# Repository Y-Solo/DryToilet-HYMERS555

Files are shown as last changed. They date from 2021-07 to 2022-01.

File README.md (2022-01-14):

# <p> Toilette sèche pour camping car HYMER S555 de 1993 </p> <i>Dry toilet for HYMER S555 motor home from 1993</i>
Conception d'une toilette sèche en remplacement de la toilette chimique d'origine.
Fabriquée essentiellement à partir de panneaux de bois en contreplaqué d'épaisseur 18mm.

<i>Design of a dry toilet to replace the original chemical toilet. Made primarily from plywood panels 18mm thick.</i>

<br>

<p align="center">
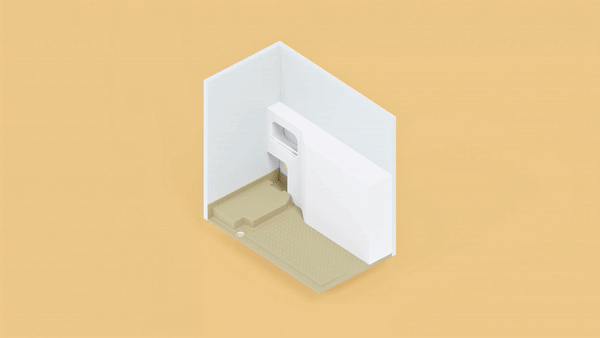
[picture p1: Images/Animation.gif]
  
</p>
<br>

Kit siège + séparateur TROBOLO® utilisé pour cette conception.
Le lien produit : https://trobolo.com/fr/produits/separateur-gris-avec-siege-de-toilette/

<i>TROBOLO® seat + divider kit used for this design.</i>
<i> The product link : https://trobolo.com/en/products/urine-diverting-toilets-insert-grey-toilet-seat/ </i>

<p align="center">
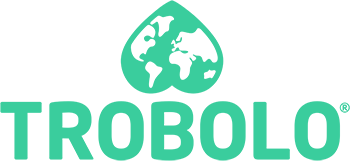
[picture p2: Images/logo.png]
  
</p>

<p align="center">
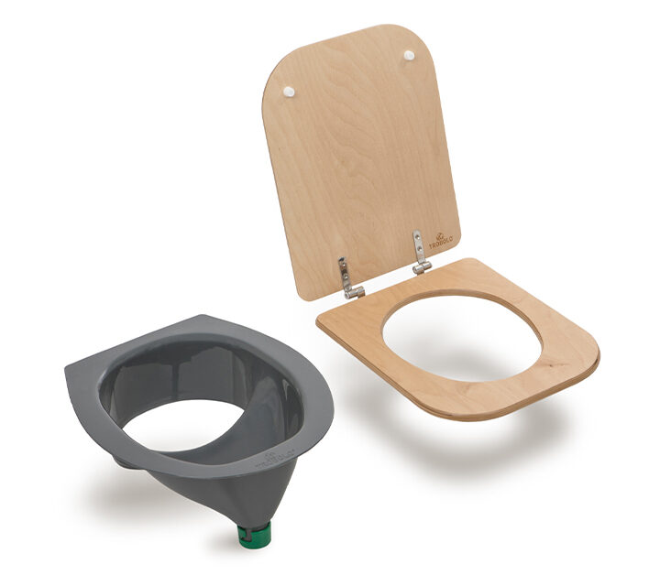
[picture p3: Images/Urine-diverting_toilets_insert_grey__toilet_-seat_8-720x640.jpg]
  
</p>

<br>

# <p> Schéma de la salle d'eau sans toilette </p> <i>Diagram of the bathroom without toilet</i>

<p align="center">
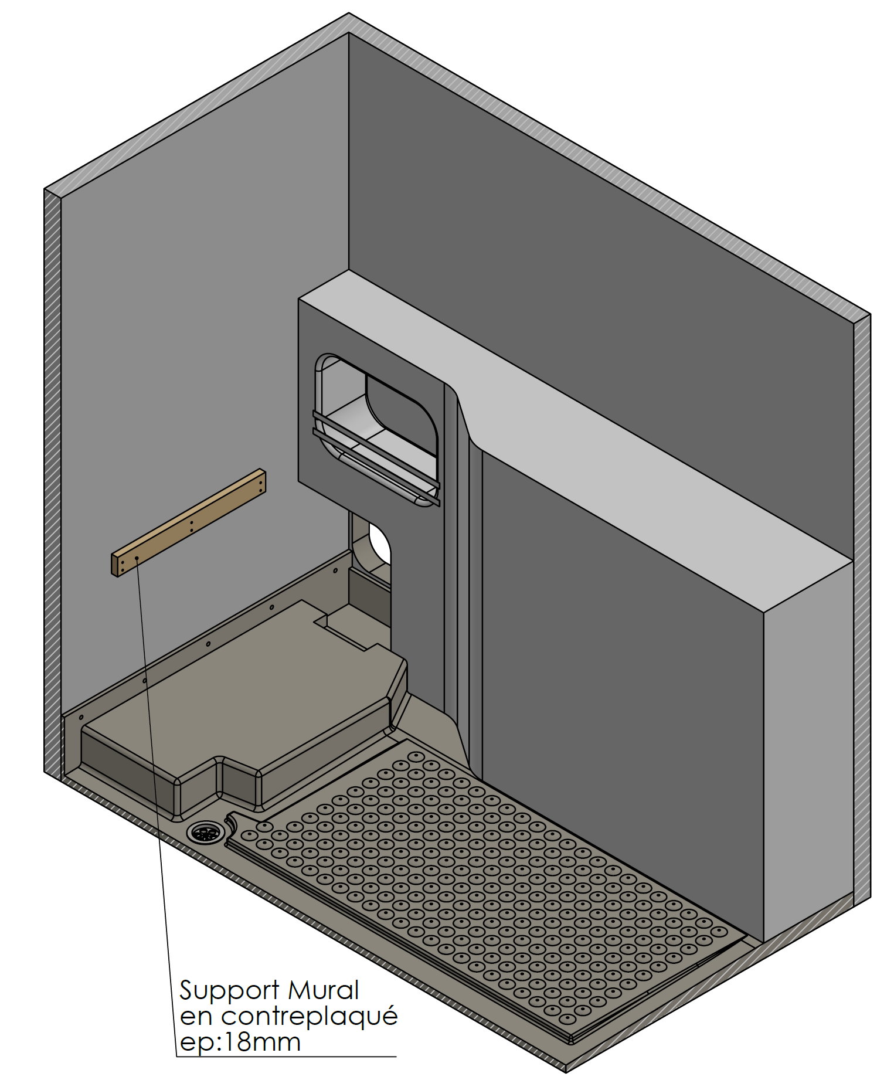
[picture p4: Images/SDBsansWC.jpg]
  
</p>
<br>
<br>

# <p> Schéma de la salle d'eau avec toilette </p> <i>Diagram of the bathroom with toilet</i>

<p align="center">
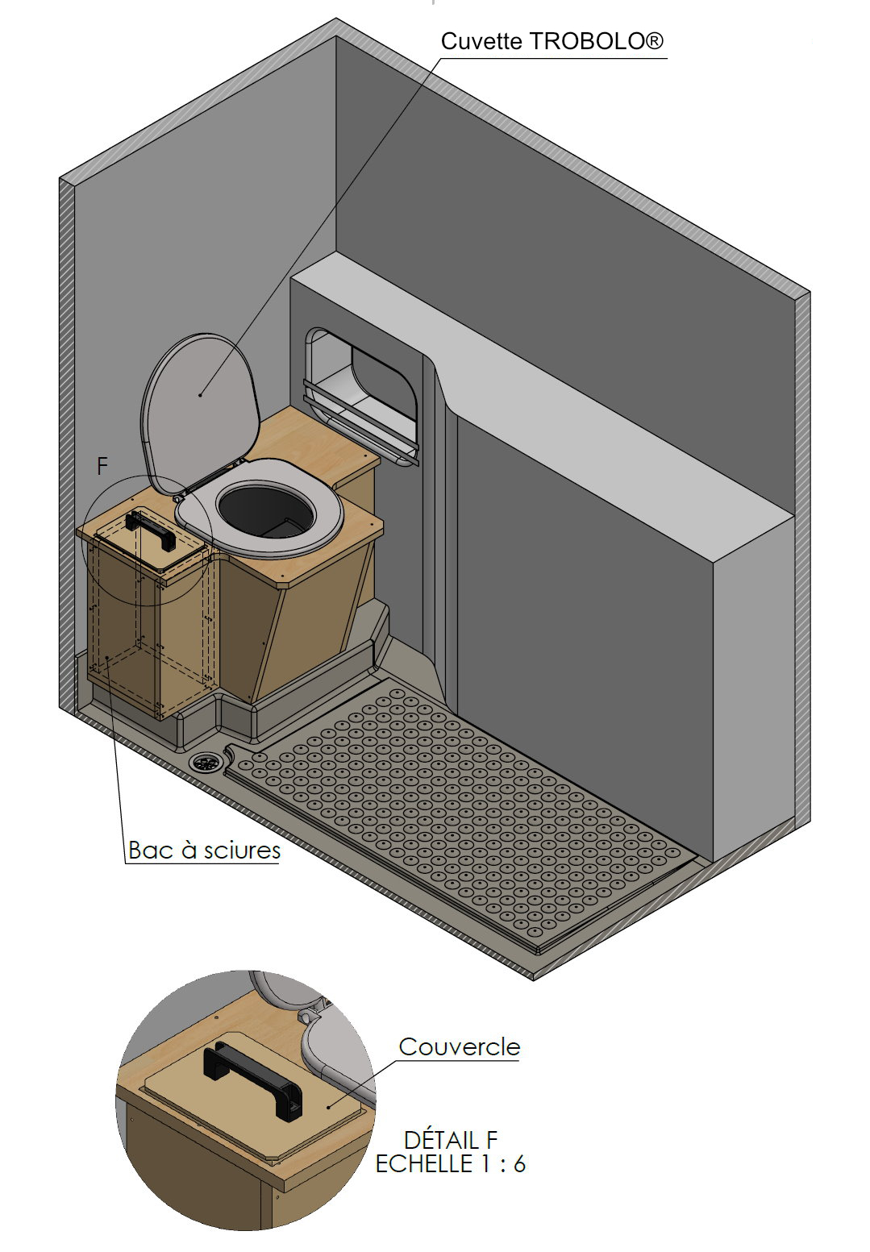
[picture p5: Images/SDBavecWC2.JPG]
  
</p>
<br>
<br>

# <p> Vue éclatée </p> <i>Exploded view</i>

<p align="center">
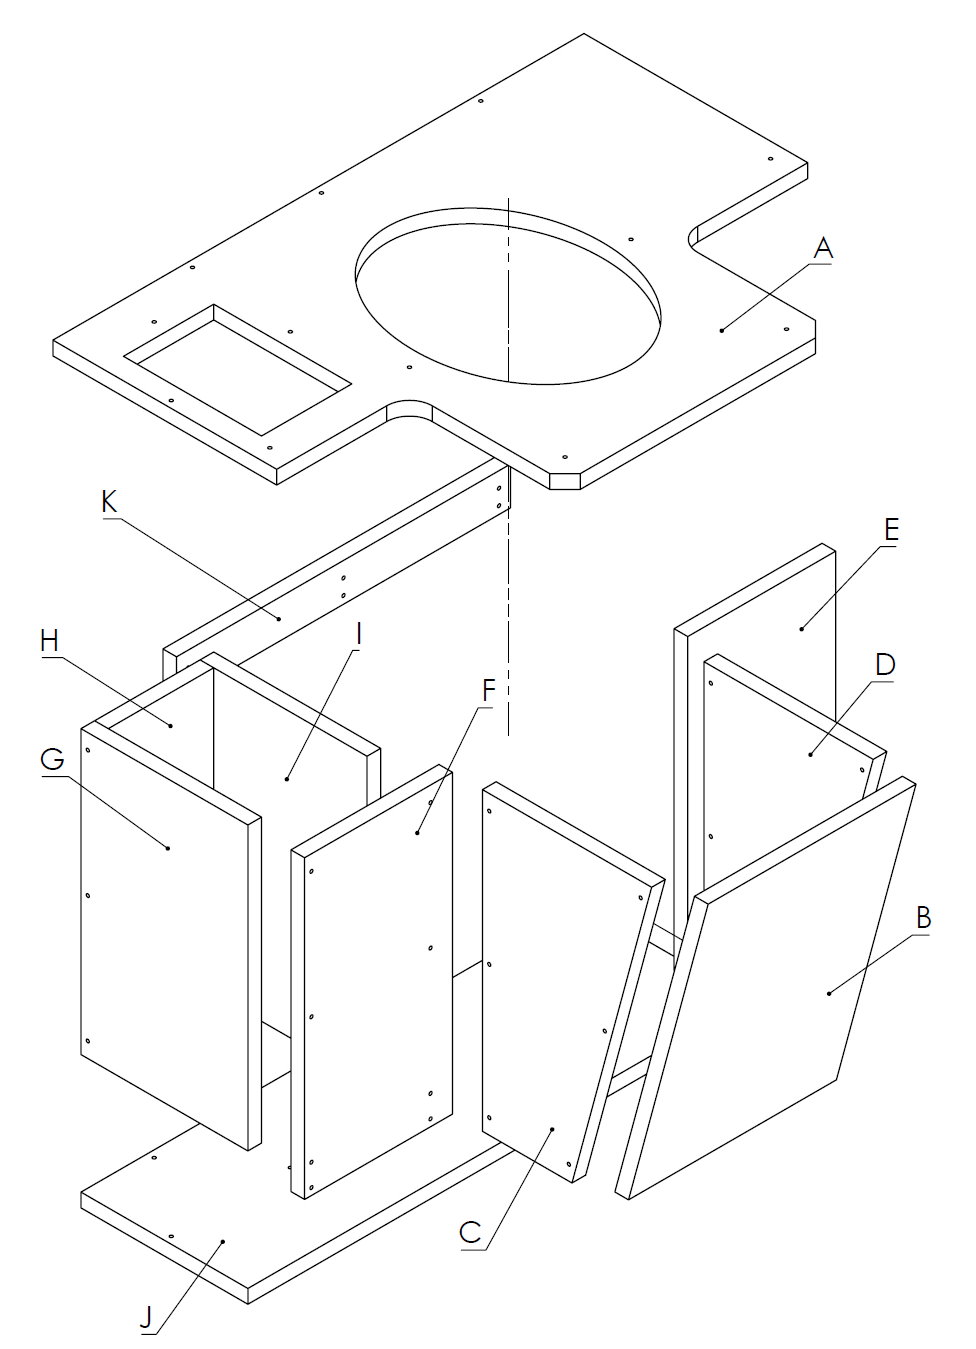
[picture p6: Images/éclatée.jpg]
  
</p>
<p> Voir le plan PDF pour correspondance des nomenclatures </p> <i> See the PDF plan for correspondence of the nomenclatures </i>
<br>
<br>

# <p> Bac à sciures </p> <i>Sawdust bin</i>

<p align="center">
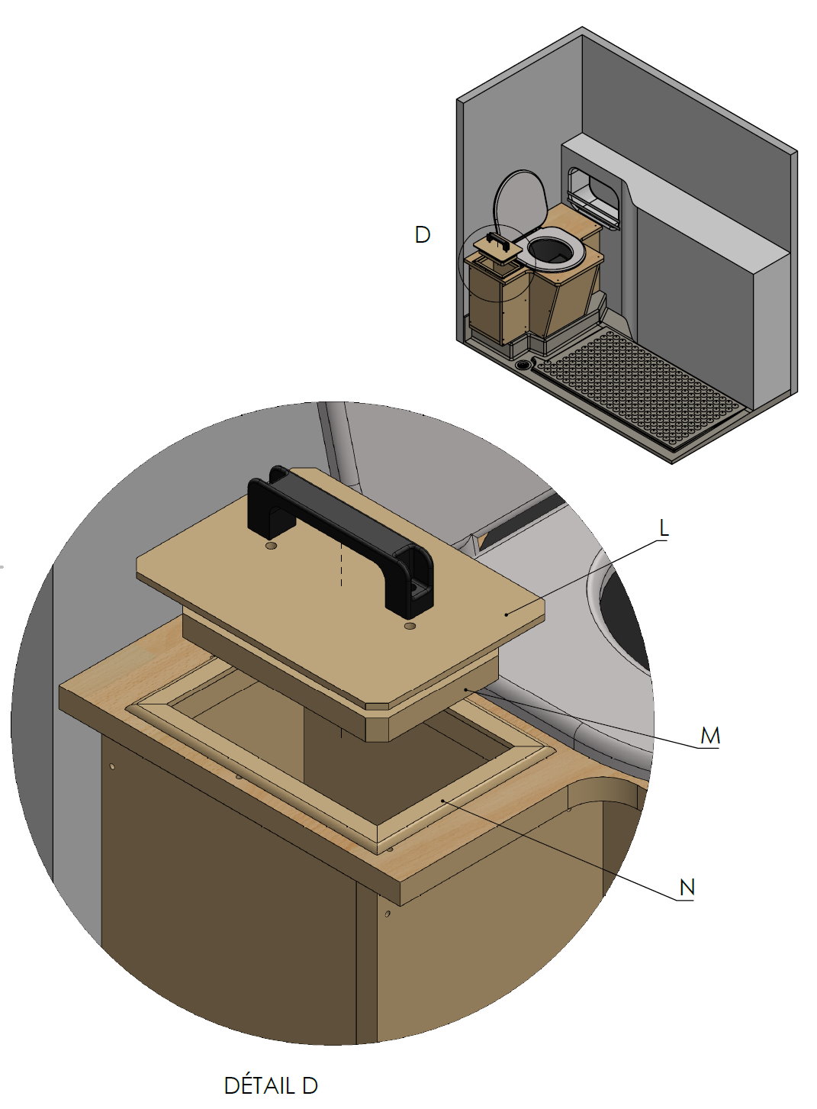
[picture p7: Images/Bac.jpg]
  
</p>
<p> Voir le plan PDF pour correspondance des nomenclatures </p> <i> See the PDF plan for correspondence of the nomenclatures </i>
<br>
<br>

# <p> Résultat final </p> <i> Final result </i>

<p align="center">
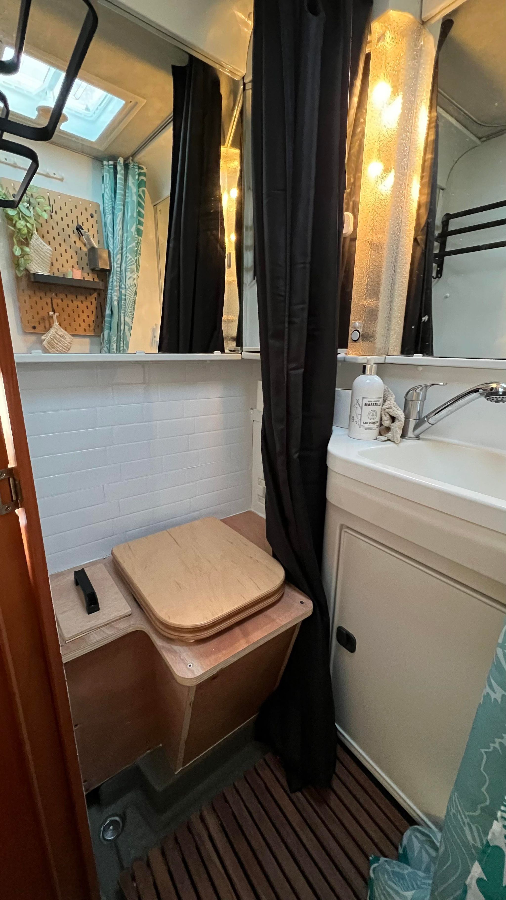
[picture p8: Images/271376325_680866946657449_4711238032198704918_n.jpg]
  
</p>

<br>

----------------------------------------------

<br>

# <p> Outils nécessaires </p> <i> Necessary tools </i>
- Scie Circulaire / <i> Circular saw </i>
- Scie Sauteuse / <i> Jigsaw </i>
- Visseuse Perceuse électrique / <i> Electric drill & screwdriver </i>
- Scie Cloche de 60mm / <i> 60mm diameter hole saw  </i>
- Mètre ruban / <i> Mesureing tape </i>
- Equerre de charpentier / <i> Carpenter's square </i>
- Grande règle en acier (60cm) / <i> Large steel ruler (60cm) </i>
- Crayon à papier / <i> Pencil </i>
- Coffret assortiment de vis à bois / <i> Wood screw assortment box </i>
- Equipements de Protection Individuel (EPI) / <i> Personal Protective Equipment (PPE) </i>

<br>

# <p> Finitions à prévoir </p> <i> Finishes to be expected </i>
- Poncer les pièces après découpe / <i> Sand the parts after cutting </i>
- Application d'un vernis epoxy pour protection du bois contre l'humidité et les projections d'eau de la douche / <i> Application of an epoxy varnish to protect the wood against humidity and splashing water from the shower </i>
- Application de joints silicones contre les infiltrations d'eau tout autour de la structure / <i> Application of silicone seals against water infiltration all around the structure </i>
- Ajout d'un joint feutre pour éviter l'infiltration d'eau dans le bac à sciures (entre les pièces L et N) / <i> Addition of a felt seal to prevent water infiltration into the sawdust bin (between parts L and N) </i>

<br>

# <p> Découpe de l'ouverture pour le séparateur </p> <i> Opening cut for the toilet bowl </i>
La découpe devra être effectuée à l'aide du gabarit en carton fourni avec la cuvette. Trobolo n'a pas pu me fournir les dimensions précises de l'ouverture à découper / 
<i> The cutout should be made using the cardboard template supplied with the toilet bowl. Trobolo do not provide me the precise dimensions of the opening to be cut. </i>

<br>

# <p> Conception, plans et visuels créés par Yannis MICHALET / ARCAD Digital </p> <i> Design, plans and visuals created by Yannis MICHALET / ARCAD Digital </i>

<br>

# https://arcad-digital.com

<br>

# <p> Projet sous licence GNU AGPLv3 </p> <i> Project under GNU AGPLv3 Licence </i>
Permissions d'utilisation / <i> Usage permissions </i> : 
- Utilisation commerciale / <i> Commercial use </i>
- Distribution 
- Modification 
- Utilisation privée / <i> Private use </i>

<br>

Conditions d'utilisation / <i> Terms of use </i> :
- Divulguer les codes sources si modification / <i> Disclose source </i>
- Mentionner l'auteur "Yannis MICHALET / ARCAD Digital" / <i>  License and copyright notice "Yannis MICHALET / ARCAD Digital" </i>

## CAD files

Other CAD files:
DryToilet-HymerS555_RevB2.x_t

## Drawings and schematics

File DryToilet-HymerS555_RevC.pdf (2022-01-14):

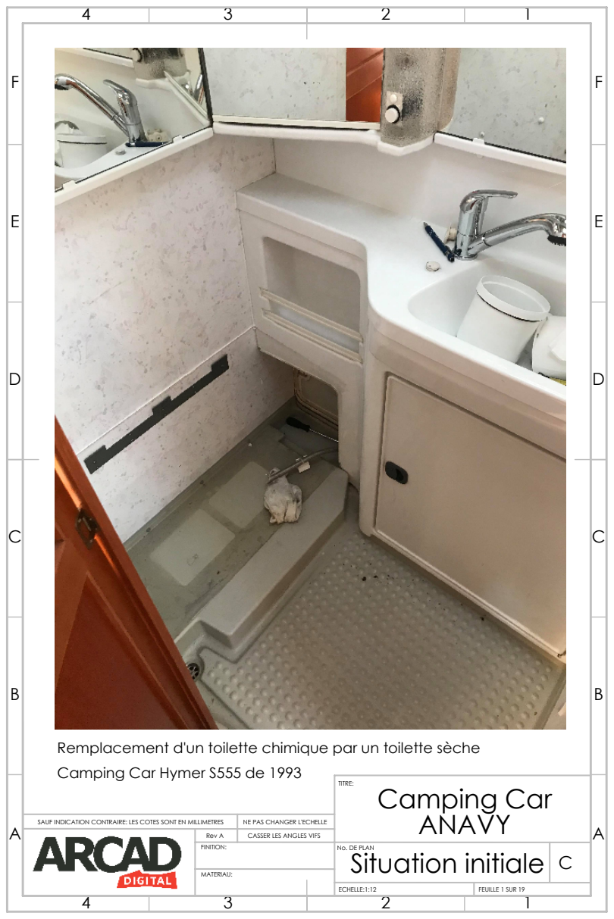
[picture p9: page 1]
Camping Car; CASSER LES ANGLES VIFS

Remplacement d'un toilette chimique par un toilette sèche
Camping Car Hymer S555 de 1993

SAUF INDICATION CONTRAIRE: LES COTES SONT EN MILLIMETRES | NE PAS CHANGER L'ECHELLE

Rev A
FINITION: | No. DE PLAN Situation initiale | C

MATERIAU:

ECHELLE:1:12 | FEUILLE 1 SUR 19

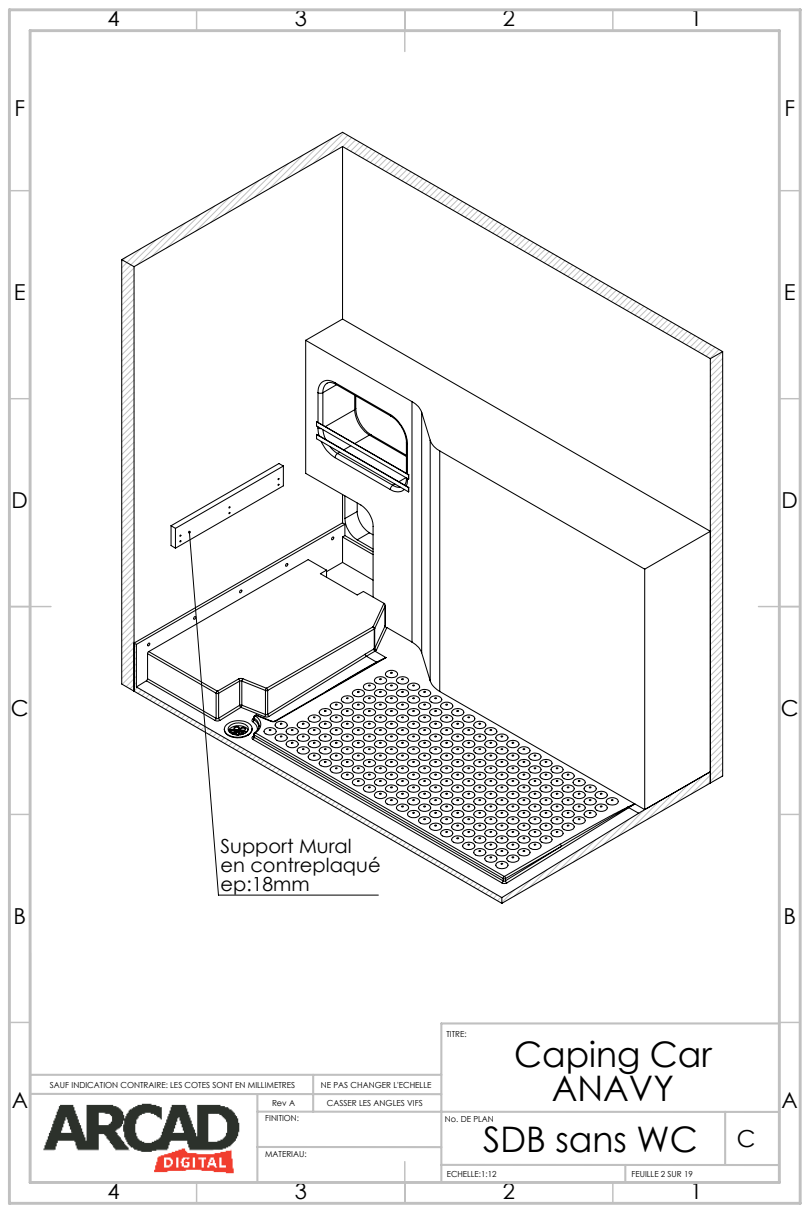
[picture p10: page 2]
Support Mural en contreplaqué; Caping Car; ECHELLE:1:12; FEUILLE 2 SUR 19; CASSER LES ANGLES VIFS

SAUF INDICATION CONTRAIRE: LES COTES SONT EN MILLIMETRES | NE PAS CHANGER L'ECHELLE

Rev A
FINITION: | SDB sans WC | C

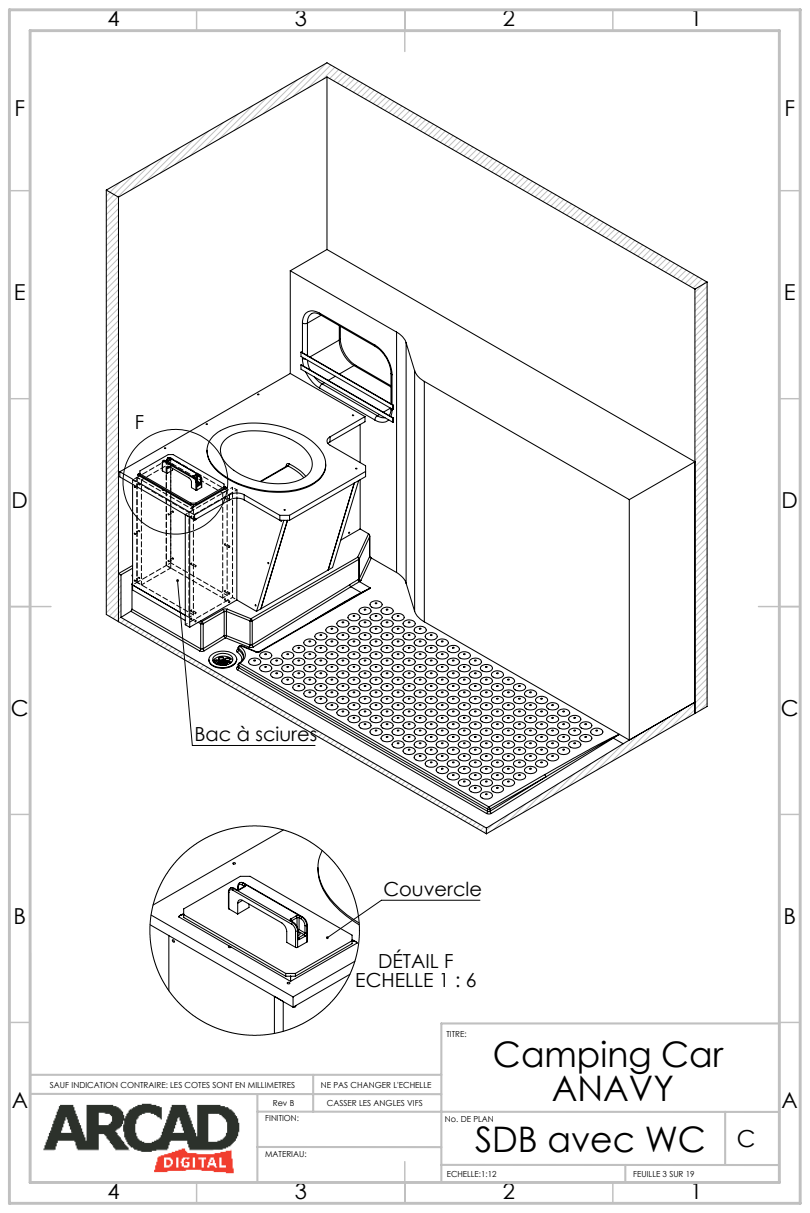
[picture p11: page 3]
Bac à sciures; DÉTAIL F ECHELLE 1 : 6; Camping Car; CASSER LES ANGLES VIFS; FEUILLE 3 SUR 19

SAUF INDICATION CONTRAIRE: LES COTES SONT EN MILLIMETRES | NE PAS CHANGER L'ECHELLE

Rev B
FINITION: | SDB avec WC | C

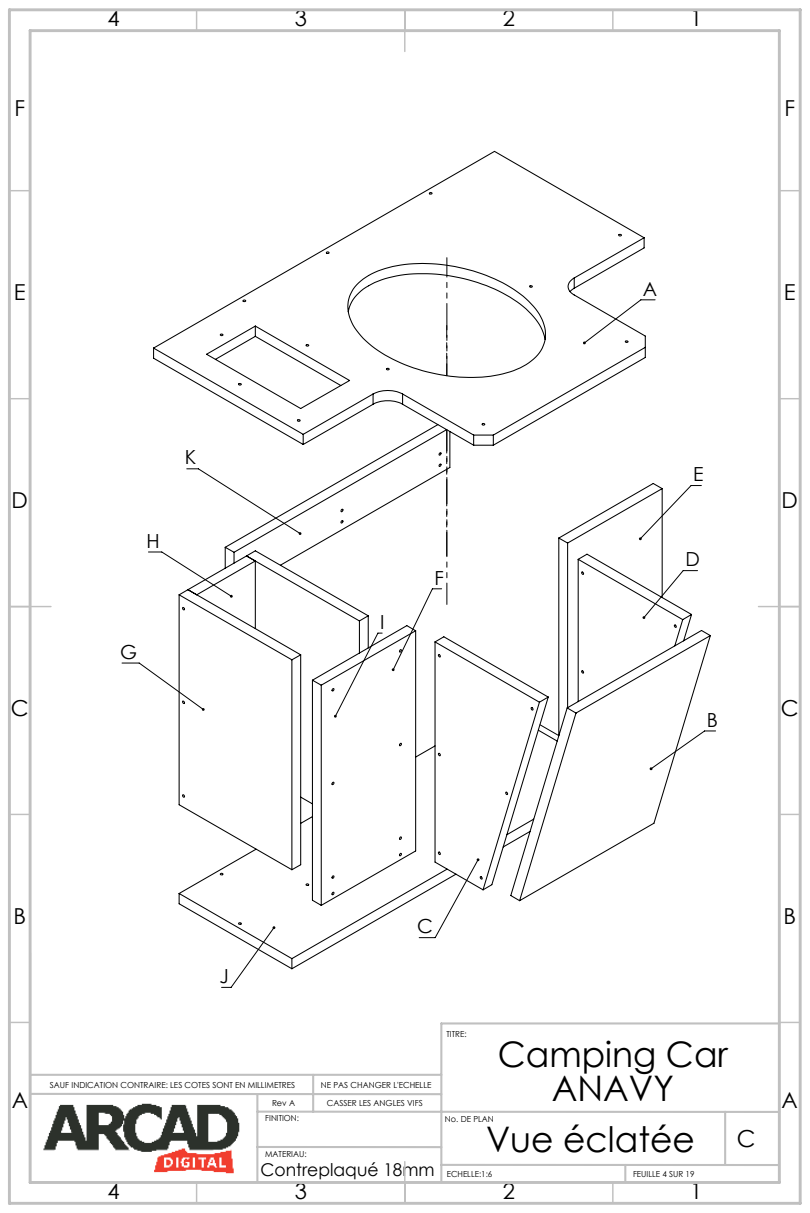
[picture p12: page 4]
Camping Car; CASSER LES ANGLES VIFS

SAUF INDICATION CONTRAIRE: LES COTES SONT EN MILLIMETRES | NE PAS CHANGER L'ECHELLE

Rev A
FINITION: | Vue éclatée | C
Contreplaqué 18mm

FEUILLE 4 SUR 19

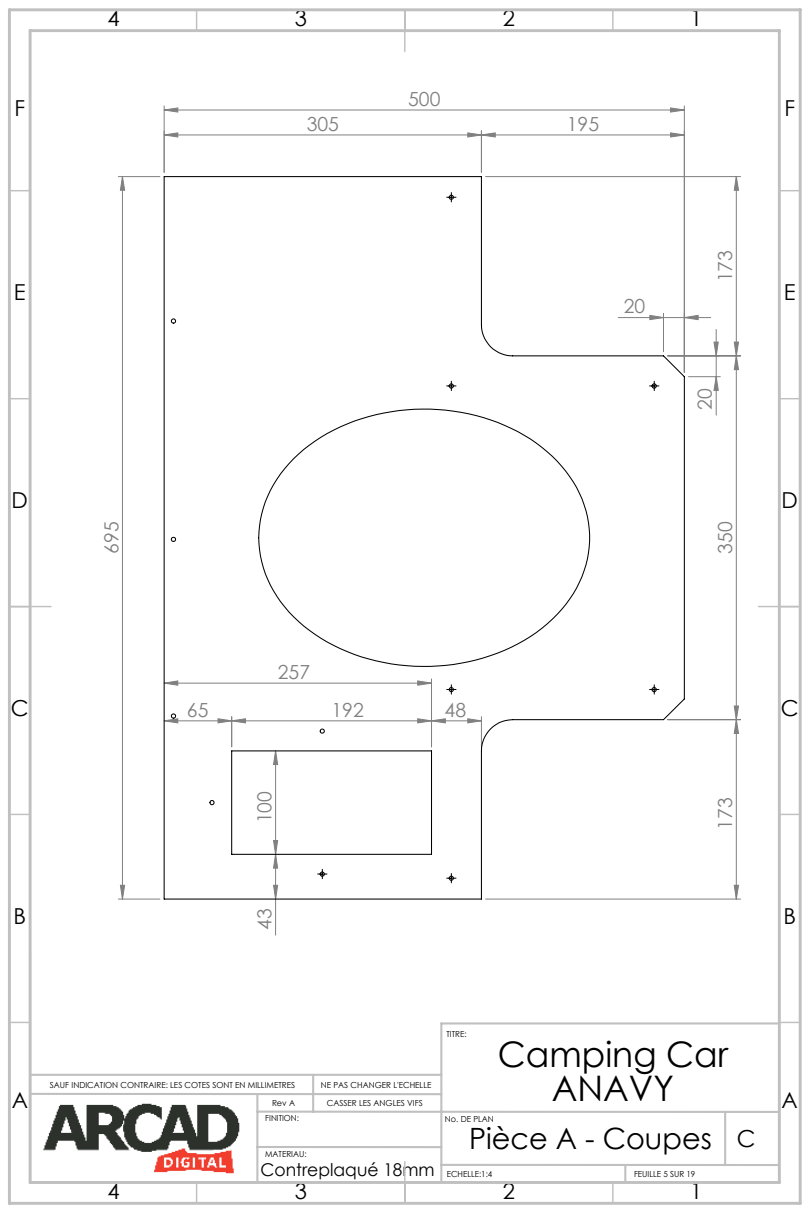
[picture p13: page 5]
Camping Car; CASSER LES ANGLES VIFS; FEUILLE 5 SUR 19

SAUF INDICATION CONTRAIRE: LES COTES SONT EN MILLIMETRES | NE PAS CHANGER L'ECHELLE

Rev A
FINITION: | Pièce A - Coupes

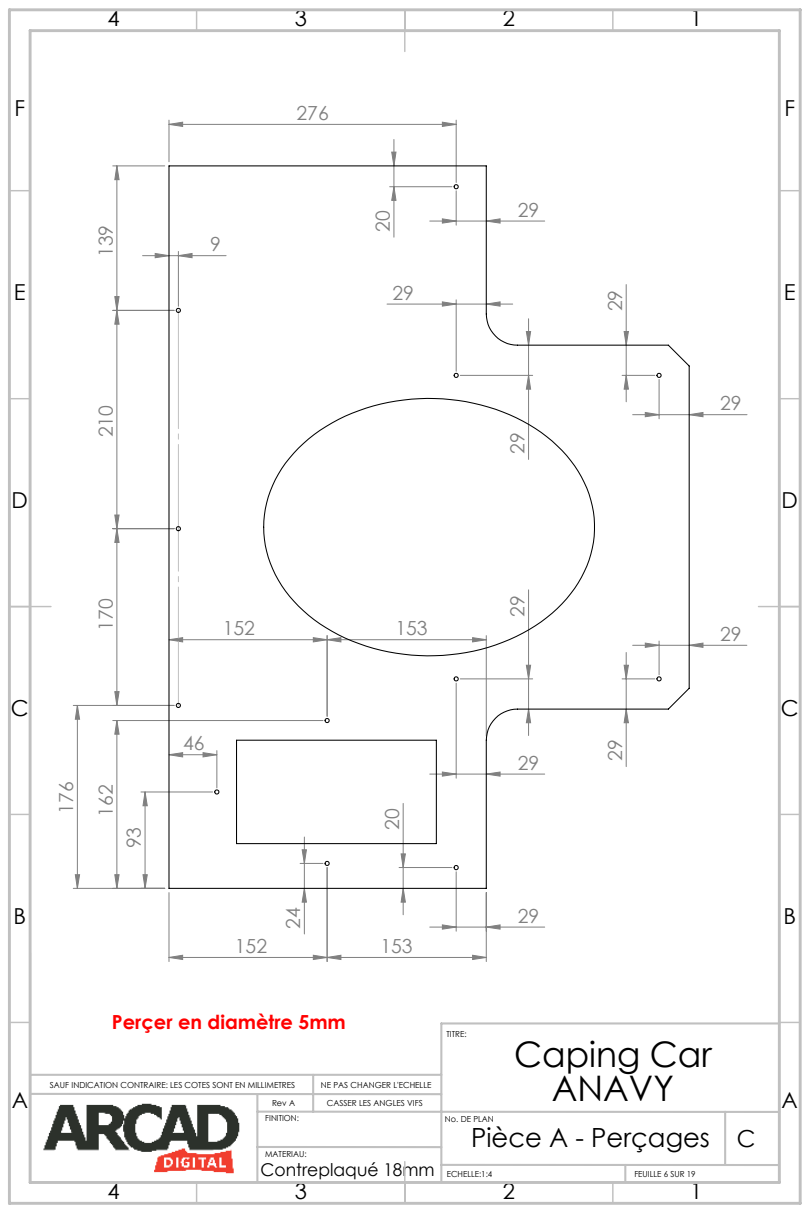
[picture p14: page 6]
Caping Car; CASSER LES ANGLES VIFS; FEUILLE 6 SUR 19

Perçer en diamètre 5mm

SAUF INDICATION CONTRAIRE: LES COTES SONT EN MILLIMETRES | NE PAS CHANGER L'ECHELLE

Rev A
FINITION: | Pièce A - Perçages

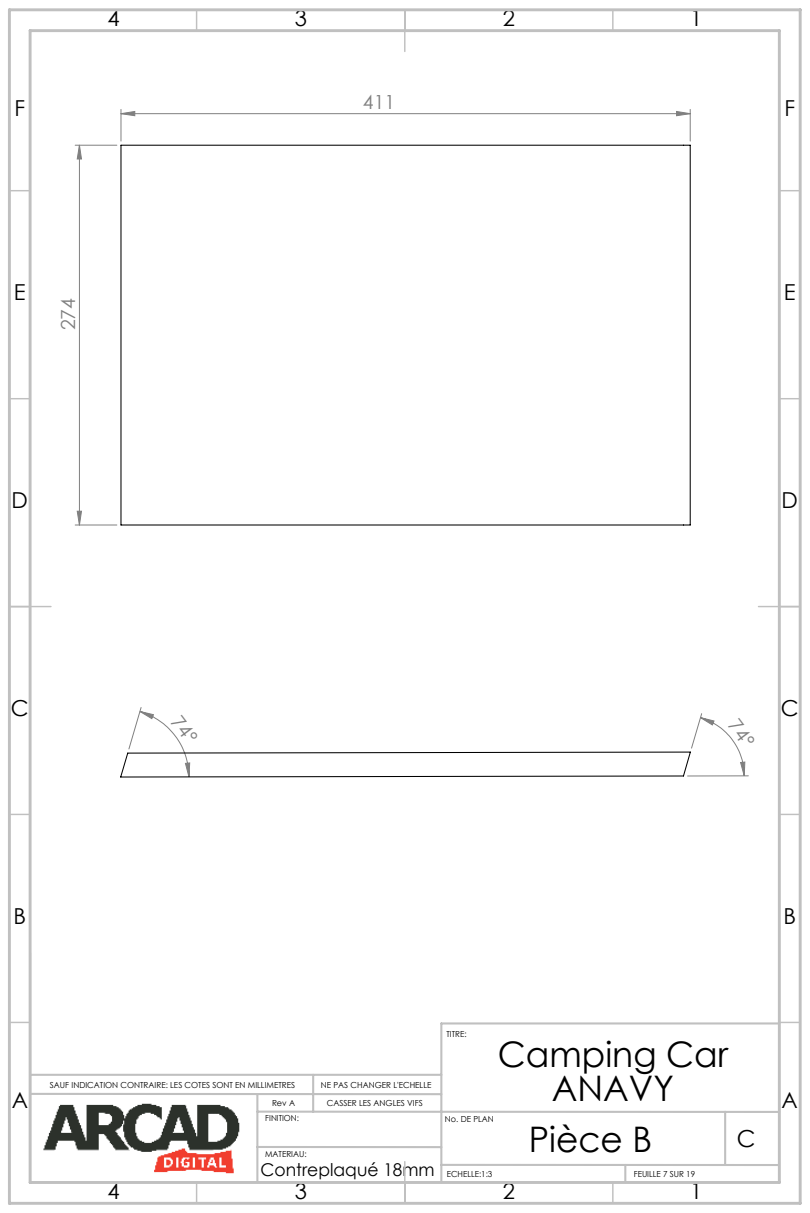
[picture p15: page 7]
Camping Car; CASSER LES ANGLES VIFS; FEUILLE 7 SUR 19

SAUF INDICATION CONTRAIRE: LES COTES SONT EN MILLIMETRES | NE PAS CHANGER L'ECHELLE

Rev A
FINITION: | Pièce B

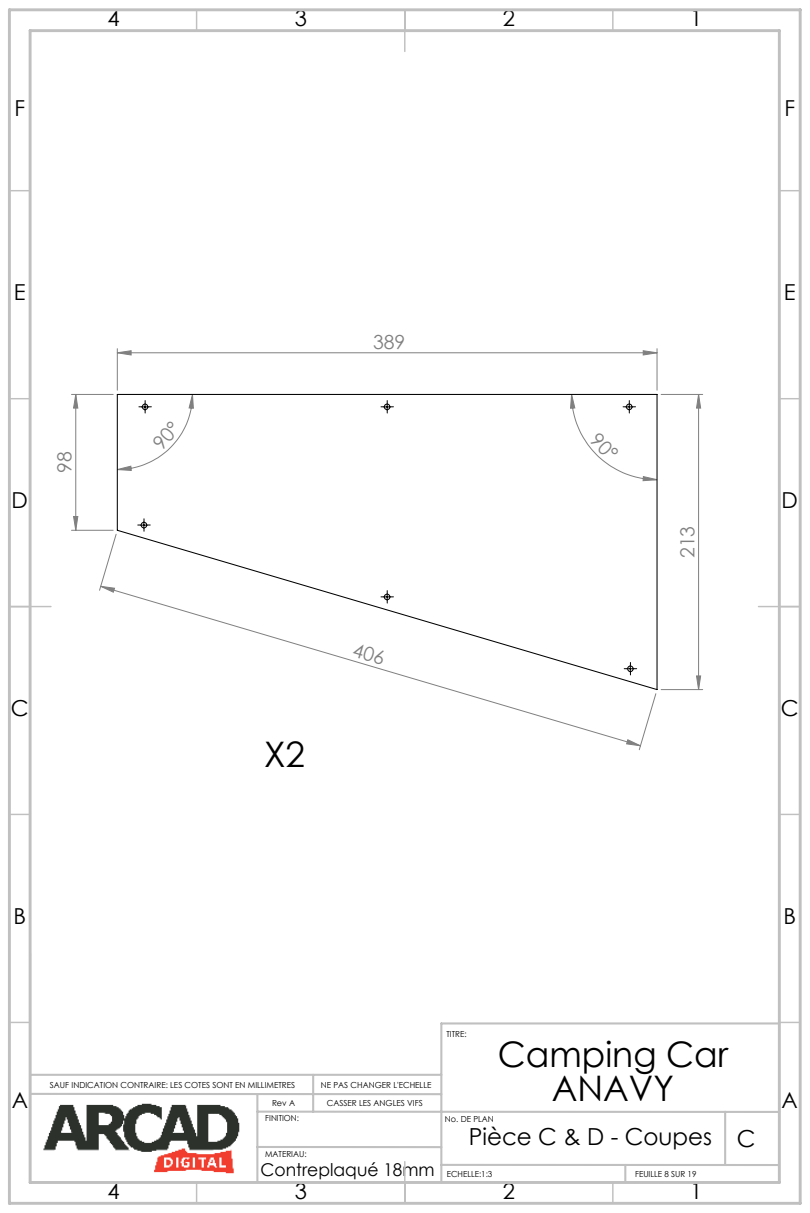
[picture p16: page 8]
Camping Car; CASSER LES ANGLES VIFS; FEUILLE 8 SUR 19

SAUF INDICATION CONTRAIRE: LES COTES SONT EN MILLIMETRES | NE PAS CHANGER L'ECHELLE

Rev A
FINITION: | Pièce C & D - Coupes

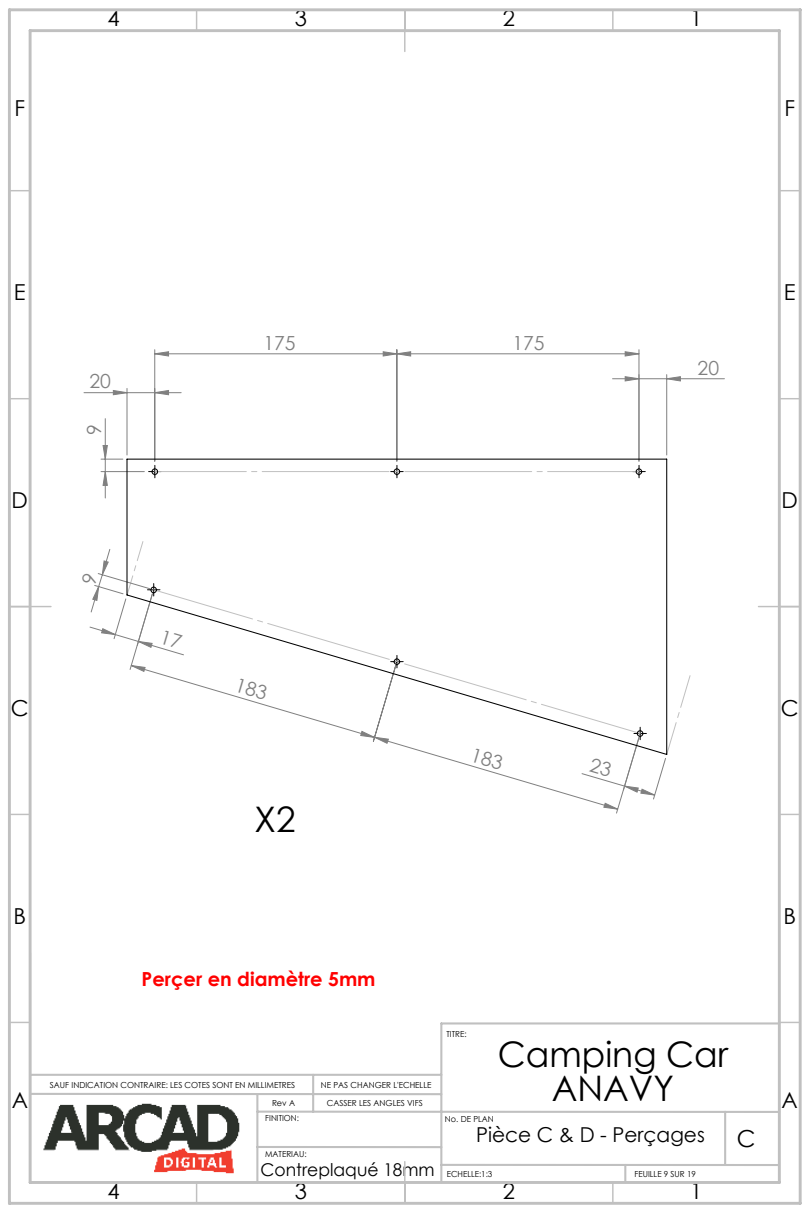
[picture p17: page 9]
Camping Car; CASSER LES ANGLES VIFS; FEUILLE 9 SUR 19

Perçer en diamètre 5mm

SAUF INDICATION CONTRAIRE: LES COTES SONT EN MILLIMETRES | NE PAS CHANGER L'ECHELLE

Rev A
FINITION: | Pièce C & D - Perçages

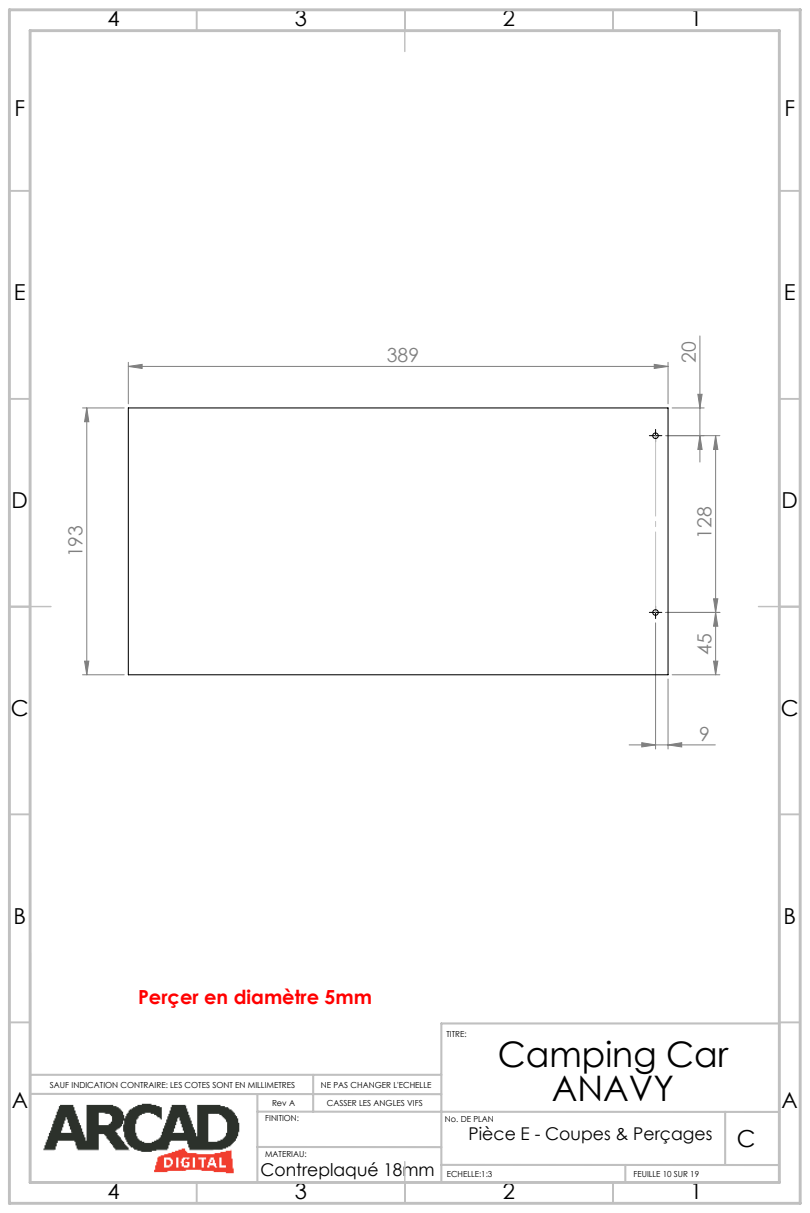
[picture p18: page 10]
Camping Car; CASSER LES ANGLES VIFS; FEUILLE 10 SUR 19

Perçer en diamètre 5mm

SAUF INDICATION CONTRAIRE: LES COTES SONT EN MILLIMETRES | NE PAS CHANGER L'ECHELLE

Rev A
FINITION: | Pièce E - Coupes & Perçages

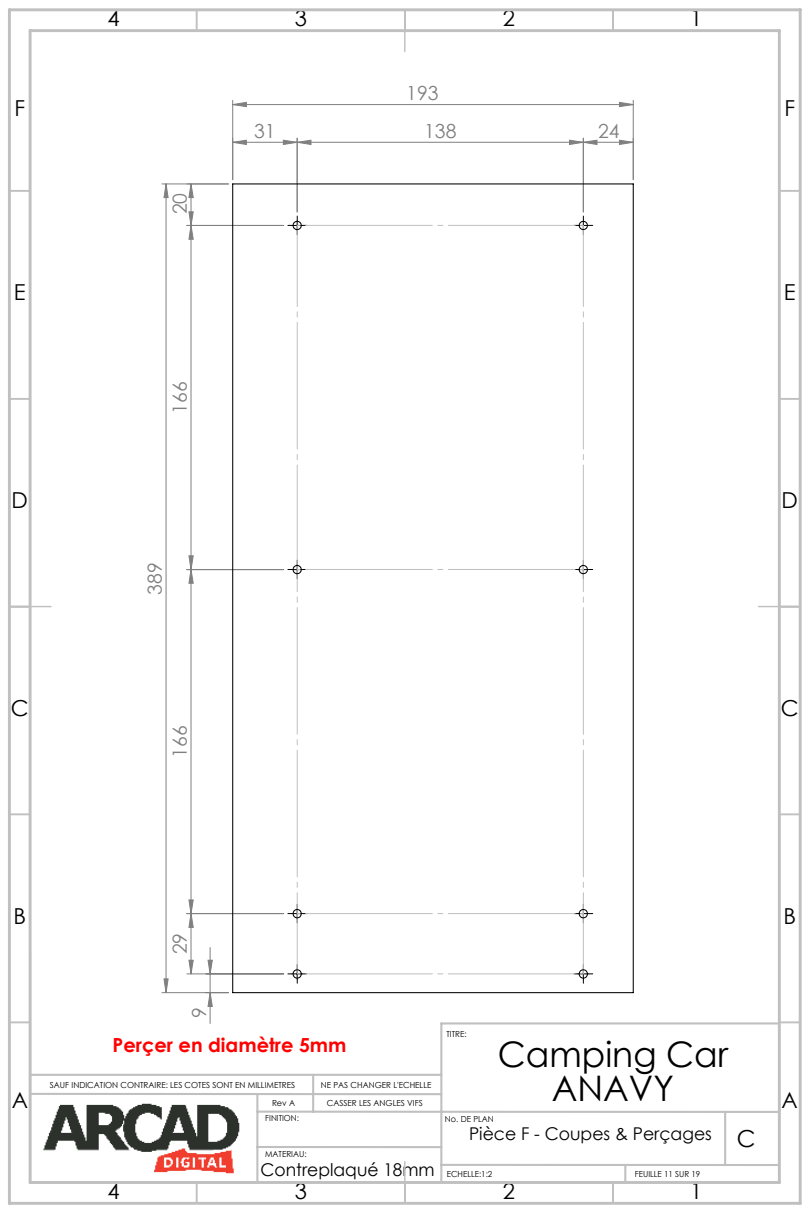
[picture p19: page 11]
Perçer en diamètre 5mm; Camping Car; CASSER LES ANGLES VIFS; FEUILLE 11 SUR 19

SAUF INDICATION CONTRAIRE: LES COTES SONT EN MILLIMETRES | NE PAS CHANGER L'ECHELLE

Rev A
FINITION: | Pièce F - Coupes & Perçages

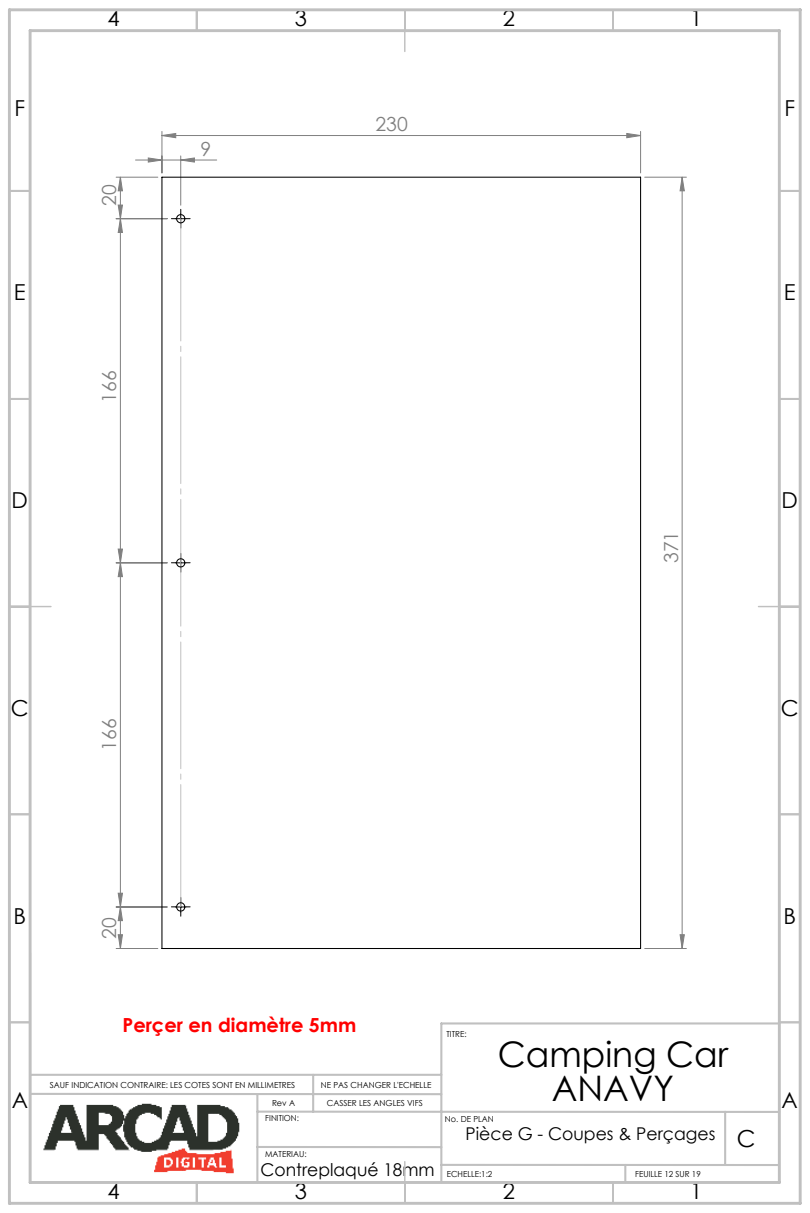
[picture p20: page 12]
Camping Car; CASSER LES ANGLES VIFS; FEUILLE 12 SUR 19

Perçer en diamètre 5mm

SAUF INDICATION CONTRAIRE: LES COTES SONT EN MILLIMETRES | NE PAS CHANGER L'ECHELLE

Rev A
FINITION: | Pièce G - Coupes & Perçages

Camping Car; CASSER LES ANGLES VIFS; FEUILLE 13 SUR 19

SAUF INDICATION CONTRAIRE: LES COTES SONT EN MILLIMETRES | NE PAS CHANGER L'ECHELLE

Rev A
FINITION: | Pièce H - Coupe & Perçages

Camping Car; CASSER LES ANGLES VIFS; FEUILLE 14 SUR 19

Perçer en diamètre 5mm

SAUF INDICATION CONTRAIRE: LES COTES SONT EN MILLIMETRES | NE PAS CHANGER L'ECHELLE

Rev A
FINITION: | Pièce I - Coupes & Perçages

Camping Car; CASSER LES ANGLES VIFS; FEUILLE 15 SUR 19

Perçer en diamètre 5mm

SAUF INDICATION CONTRAIRE: LES COTES SONT EN MILLIMETRES | NE PAS CHANGER L'ECHELLE

Rev A
FINITION: | Pièce J - Coupes & Perçages

Camping Car; CASSER LES ANGLES VIFS; FEUILLE 16 SUR 19

Perçer en diamètre 5mm

SAUF INDICATION CONTRAIRE: LES COTES SONT EN MILLIMETRES | NE PAS CHANGER L'ECHELLE

Rev A
FINITION: | Pièce K - Coupes & Perçages

DÉTAIL D; Camping Car; CASSER LES ANGLES VIFS; FEUILLE 17 SUR 19

SAUF INDICATION CONTRAIRE: LES COTES SONT EN MILLIMETRES | NE PAS CHANGER L'ECHELLE

Rev A
FINITION: | Finitions bac à sciures | C

Pièce M - Contreplaqué 18mm; Camping Car; CASSER LES ANGLES VIFS; FEUILLE 18 SUR 19

Pièce L - Planche bois 5mm

SAUF INDICATION CONTRAIRE: LES COTES SONT EN MILLIMETRES | NE PAS CHANGER L'ECHELLE

Rev A
FINITION: | Pièces L & M | C

Camping Car; Champlat 4x18mm; CASSER LES ANGLES VIFS; FEUILLE 19 SUR 19

SAUF INDICATION CONTRAIRE: LES COTES SONT EN MILLIMETRES | NE PAS CHANGER L'ECHELLE

Rev A
FINITION: | Pièces N
